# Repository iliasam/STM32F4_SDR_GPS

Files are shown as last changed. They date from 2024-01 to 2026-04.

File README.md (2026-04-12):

# STM32F4_SDR_GPS

Software GPS receiver for STM32F4  
See article (in Russian): https://habr.com/ru/articles/789382/  
You can find same project for **ESP32** here: https://github.com/iliasam/ESP32_SDR_GPS  
  
This is a demo project of STM32-based SDR GPS receiver.  
No additional factory/commercial "black box" GPS receiver is needed here - just connect MAX2769 (GNSS RF Frontend IC) to the STM32 MCU.  
All "raw" GPS signal processing is done at the STM32.  
Results of the GPS signal processing are send to the UART:   
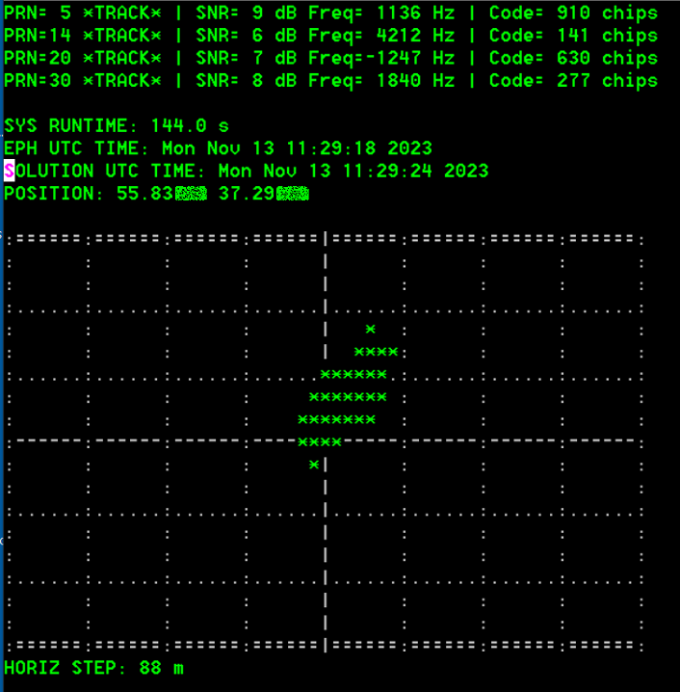
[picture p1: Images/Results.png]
  
This is what the receiver looks like:  
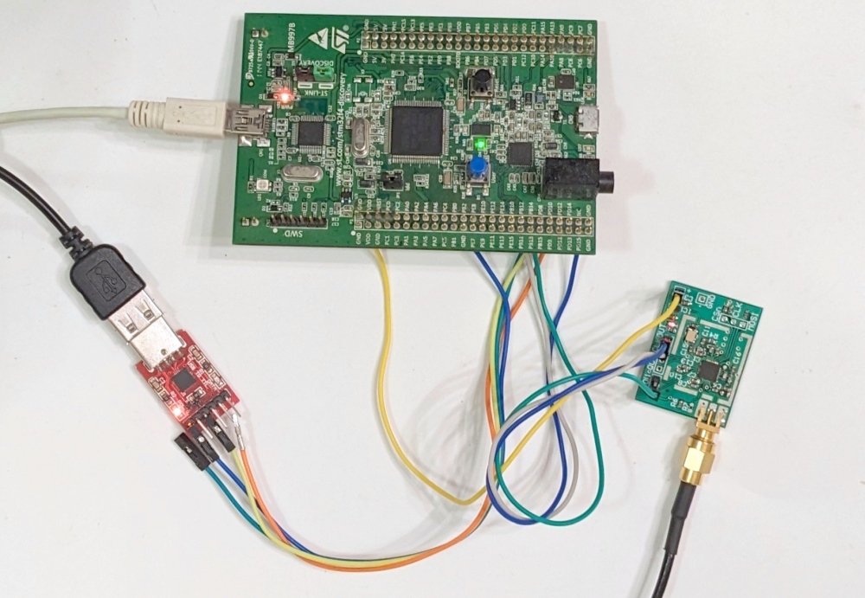
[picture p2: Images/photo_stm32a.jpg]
  
  
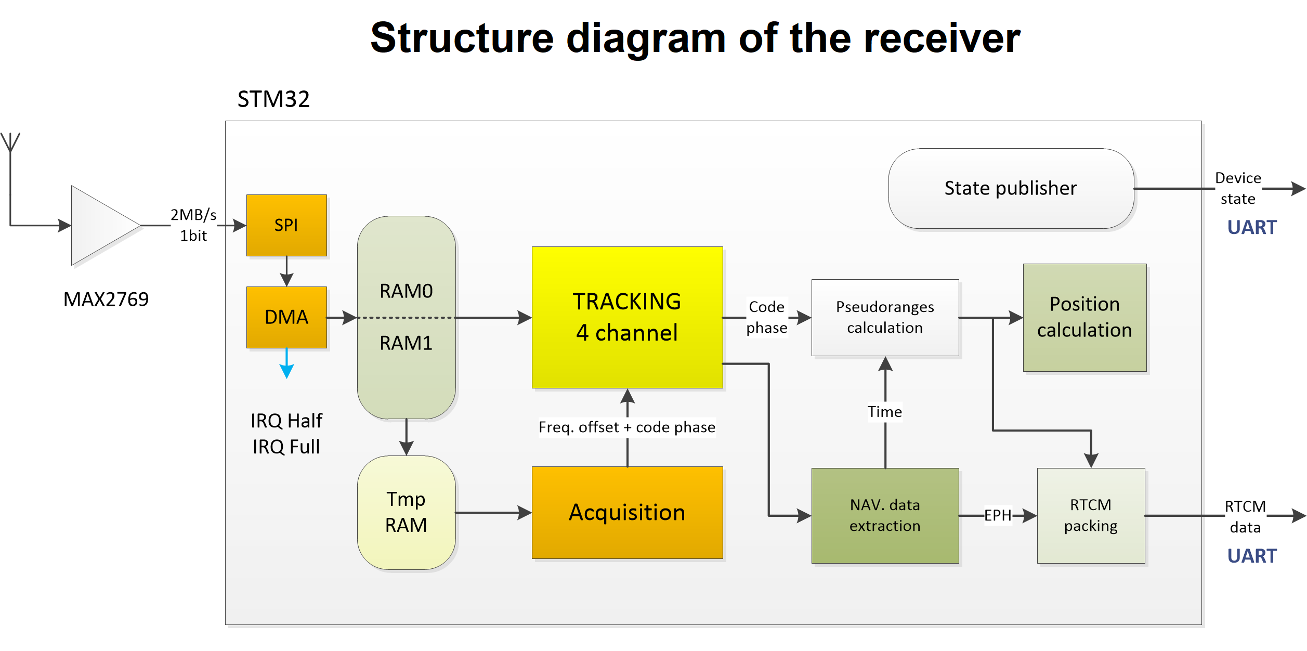
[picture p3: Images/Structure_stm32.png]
  
  
**Video about this project:**  
https://youtu.be/1hBnaDsQgMc  
  
Configured for STM32F4-DISCOVERY dev. board.  
-Os optimization is used here  

User must set PRN codes of 4 satellites in the code - before compiling FW (I'm too lazy to create real CLI).  
User can set Doppler frequency offsets in the code to make acquisition much faster.  
  
RF frontend pinout (See config.h):  
#define SPI_CLK_PIN             GPIO_Pin_13 //MAX2769 - CLKOUT  
#define SPI_MOSI_PIN            GPIO_Pin_15 //MAX2769 - I1  
Both - GPIOB  

Part of the code is taken from these projects:  
https://github.com/tomojitakasu/RTKLIB  
https://github.com/taroz/GNSS-SDRLIB

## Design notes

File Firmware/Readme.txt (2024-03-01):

"project_single_sat" - example of using only one satellite. PRN is set in "main.c"
It is simplier, but has less comments.
This firmware can parse only "Subframe 1".
Current time is printed when "Subframe 1" has received.  

UART is not used here, "printf" is redirected to the SWO line - see compiler options.
Stack - 0x2000
Heap - 0x200

Compiler output:
30 642 bytes of readonly  code memory 
   220 bytes of readonly  data memory 
89 713 bytes of readwrite data memory 

Example of SWO output:
SAT=5
FINAL FREQ=1000 Hz
FINAL ACQ (SRCH_3) CODE=1990
START PRE_TRACK
FOUND TRACK PHASE=1991
PREAMBLE!
POLAR. FOUND
SUB ID=2
PREAMBLE!
SUB ID=3
PREAMBLE!
SUB ID=4
PREAMBLE!
SUB ID=5
PREAMBLE!
SUB ID=1
Curr. Time = Mon Nov 13 11:28:18 2023
PREAMBLE!
SUB ID=2

*********************

"project_main" - example of using 4 satellites, including localization. PRN is set in "main.c"

RTCM/Receiving state information is send to the UART, but "printf" is still redirected to the SWO line.

Stack - 0x2000
Heap - 0x1000 (needed for localization)

Compiler output:
 67 978 bytes of readonly  code memory 
    301 bytes of readonly  data memory 
105 958 bytes of readwrite data memory 

******************

IAR 7.50 is used here

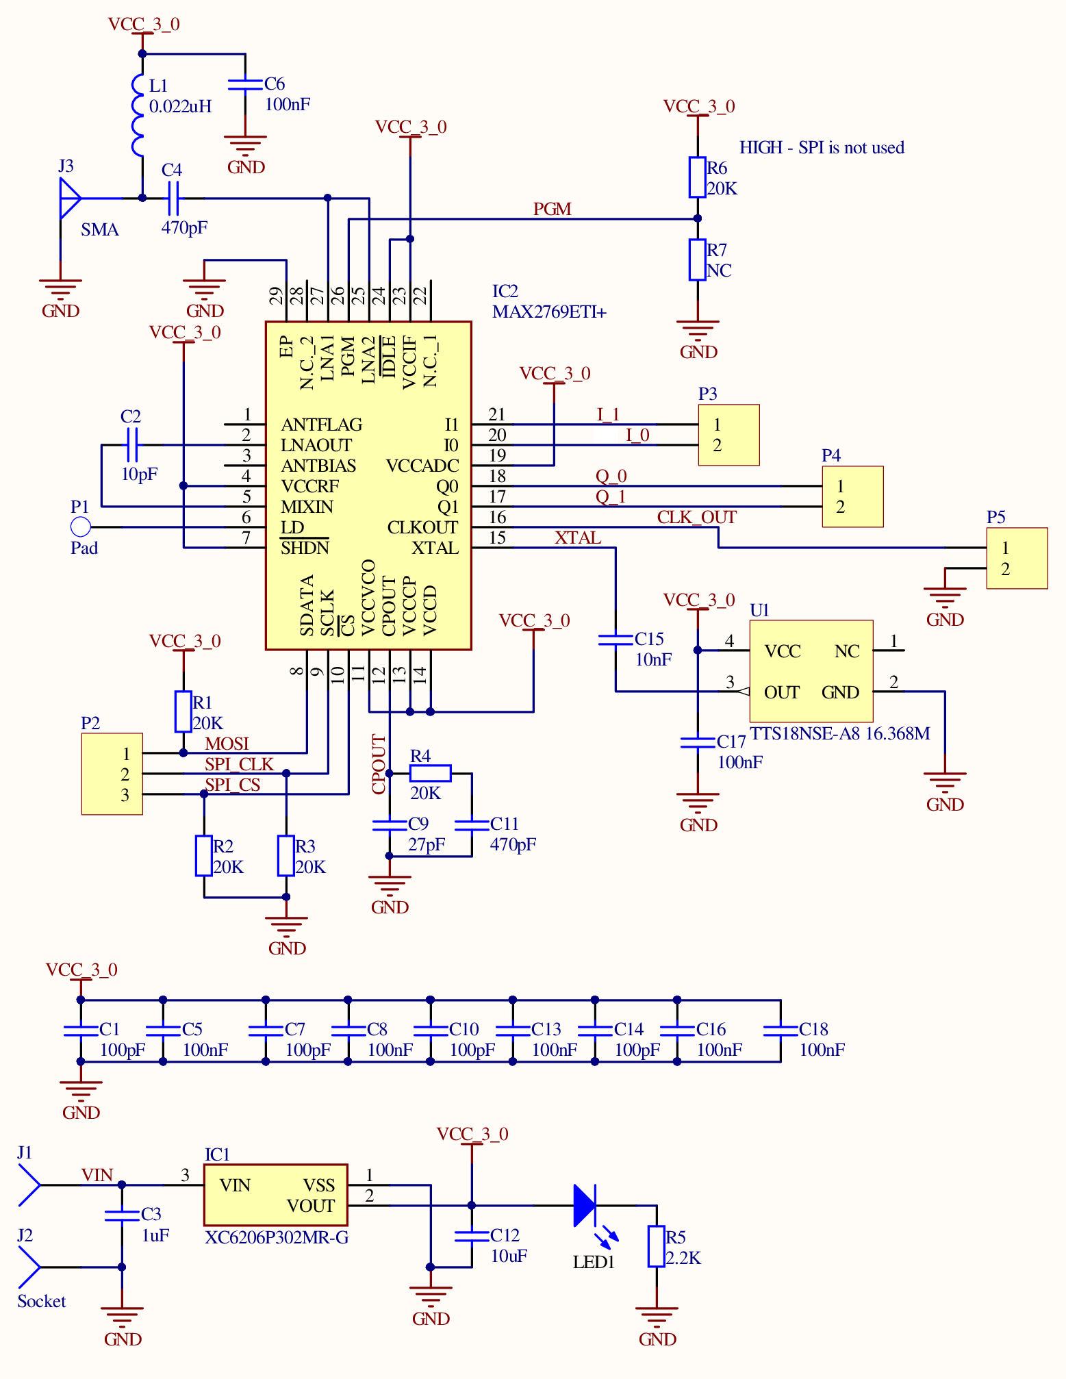
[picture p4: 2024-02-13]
RF_Frontend/schematic.png

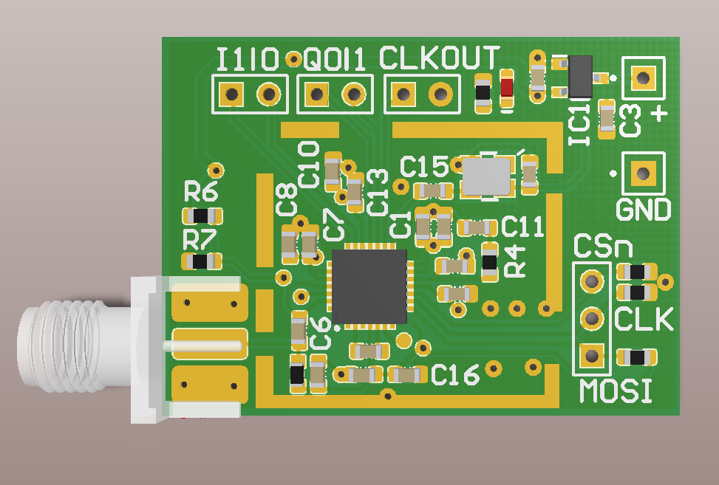
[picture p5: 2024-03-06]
RF_Frontend/image.png

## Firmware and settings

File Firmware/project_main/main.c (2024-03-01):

//Single satellite acquisition and tracking. 
//Printf is using semihosting via SWO (configured in )

/* Includes ------------------------------------------------------------------*/
#include "main.h"
#include "stm32f4xx_rcc.h"
#include "delay_us_timer.h"
#include "gps_misc.h"
#include "config.h"
#include "signal_capture.h"
#include "common_ram.h"
#include "acquisition.h"
#include "tracking.h"
#include "gps_master.h"
#include "uart_comm.h"
#include "print_state.h"
#include "keys_controlling.h"
#include <stdio.h>
#include <stdlib.h>
#include <math.h>
#include <string.h>

#if (ENABLE_RTCM_SEND)
  #include "obs_publish.h"
#endif

#if (ENABLE_CALC_POSITION)
  #include "solving.h"
#endif

/* Private typedef -----------------------------------------------------------*/
/* Private define ------------------------------------------------------------*/
/* Private macro -------------------------------------------------------------*/
/* Private variables ---------------------------------------------------------*/
gps_ch_t gps_channels[GPS_SAT_CNT];

/* Private function prototypes -----------------------------------------------*/
void main_process_acq_data(void);

void main_slow_data_proc(void);
void main_fast_data_proc(void);

/* Private functions ---------------------------------------------------------*/

int main(void)
{
  RCC_ClocksTypeDef RCC_Clocks;
  RCC_GetClocksFreq(&RCC_Clocks);
  NVIC_PriorityGroupConfig(NVIC_PriorityGroup_0); //4 bits for subpriority
  dwt_init();
  
  gps_fill_summ_table();
  
  memset(&gps_channels[0], 0, sizeof(gps_channels));
  
  //solve_test();
  
  // user can enter known doppler frequency to make acquisition much faster
  gps_channels[0].prn = 5;
  gps_channels[0].acq_data.given_freq_offset_hz = 900;
  gps_channell_prepare(&gps_channels[0]);
  
  gps_channels[1].prn = 14;
  gps_channels[1].acq_data.given_freq_offset_hz = 4000;
  gps_channell_prepare(&gps_channels[1]);
  
  gps_channels[2].prn = 20;
  gps_channels[2].acq_data.given_freq_offset_hz = -1000;
  gps_channell_prepare(&gps_channels[2]);
  
  gps_channels[3].prn = 30;
  gps_channels[3].acq_data.given_freq_offset_hz = 2000;
  gps_channell_prepare(&gps_channels[3]);
  
#if (ENABLE_CALC_POSITION)
  gps_pos_solve_init(gps_channels);
#endif
  
  uart_init();
  keys_init();
  signal_capture_init();
  
  signal_capture_need_data_copy();
  print_state_prepare(gps_channels);
  
  while(1)
  {
    uint8_t need_slow = gps_master_need_acq();
    if (need_slow > 0)
    {
      //Not realtime
      main_slow_data_proc();
    }
    else
    {
      //Realtime!
      uint8_t have_new_data = signal_capture_have_irq();
      if (have_new_data)
      {
        main_fast_data_proc();
      }
    }
    key_handling();
  }//end of while(1)
  
}//end of main()

//*********************************

// Acqusition data capure and process - not realtime
void main_slow_data_proc(void)
{
  uint8_t have_data = signal_capture_check_copied();
  if (have_data == 0)
  {
    //wait for IRQ
    while (signal_capture_have_irq() == 0) 
    {
      asm("nop");
    }
    
    //Process IRQ, data copy
    signal_capture_handling();
  }
  else
  {
    //have new data
    main_process_acq_data();
    signal_capture_need_data_copy();
  }
}

//Tracking
void main_fast_data_proc(void)
{
  uint8_t* signal_p = signal_capture_get_ready_buf();
  uint32_t time_cnt = signal_capture_get_packet_cnt();
  
  //4 channel multiplexing
  uint32_t index_big = time_cnt % (TRACKING_CH_LENGTH * GPS_SAT_CNT + 1); //real index, 0-16 range
  
  uint8_t sat_index = index_big / TRACKING_CH_LENGTH;
  if (sat_index >= GPS_SAT_CNT)
    sat_index = 0;
  
  uint32_t index = 0;
  if (index_big == (TRACKING_CH_LENGTH * GPS_SAT_CNT))
    index = 0xFF;
  else
  {
    index = index_big % TRACKING_CH_LENGTH;
  }
  
  //"index" can be 0-3 or 0xFF
  gps_tracking_process(&gps_channels[sat_index], signal_p, (uint8_t)index);
  
  gps_master_handling(gps_channels, index);
}


// Acquisition data process
// Can be long!
void main_process_acq_data(void)
{
  uint8_t* signal_p = signal_capture_get_copy_buf();
  acquisition_process(&gps_channels[0], signal_p);
  gps_master_handling(gps_channels, 0);
}

///////////////////////////////////

/*
int putchar(int c)
{
  return c;    
}
*/


void delay_ms(uint32_t ms)
{
  volatile uint32_t nCount;
  RCC_ClocksTypeDef RCC_Clocks;
  RCC_GetClocksFreq (&RCC_Clocks);
  nCount=(RCC_Clocks.HCLK_Frequency/10000)*ms;
  for (; nCount!=0; nCount--);
}

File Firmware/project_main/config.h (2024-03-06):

#ifndef _CONFIG_H
#define _CONFIG_H

//MCU speed is 168MHz
#define CPU_TICKS_US            (168)

#define SPI_NAME                SPI2
#define SPI_PRESCALER           SPI_BaudRatePrescaler_4
#define SPI_DMA_STREAM          DMA1_Stream3
#define SPI_DMA_CH              DMA_Channel_0
#define SPI_DMA_IRQ             DMA1_Stream3_IRQn
#define SPI_DMA_IRQ_HANDLER     DMA1_Stream3_IRQHandler

#define SPI_GPIO_CLK            RCC_AHB1Periph_GPIOB
#define SPI_CLK_PIN             GPIO_Pin_13 //MAX2769 - CLKOUT
#define SPI_MOSI_PIN            GPIO_Pin_15 //Slave Input! MAX2769 - I1 - sign
#define SPI_CLK_PIN_SRC         GPIO_PinSource13
#define SPI_MOSI_PIN_SRC        GPIO_PinSource15
#define SPI_AFIO                GPIO_AF_SPI2
#define SPI_GPIO                GPIOB


#define IF_FREQ_HZ              (int)(4092000)
#define SPI_BAUDRATE_HZ         (int)(16368000)
#define PRN_SPEED_HZ            1000 //1ms period
#define BITS_IN_PRN             (SPI_BAUDRATE_HZ / PRN_SPEED_HZ) //16Kbit
#define PRN_SPI_WORDS_CNT       (BITS_IN_PRN / 16) //1023 16bit words
#define PRN_LENGTH              1023 //in chips

#define ENABLE_RTCM_SEND        0

//Calculate receiver position by observations
#define ENABLE_CALC_POSITION    1

// Accurate code phase averaging
#define ENABLE_CODE_FILTER      1
//Number of measurements, speed is 25 measurements in one channel per 100ms
#define CODE_FILTER_LENGTH      100


#define ACQ_SEARCH_FREQ_HZ      (7000) //Frequency Search zone is x2. Doppler offset
#define ACQ_SEARCH_STEP_HZ      (500)
/// Number of freq steps
#define ACQ_COUNT       (ACQ_SEARCH_FREQ_HZ * 2 / ACQ_SEARCH_STEP_HZ + 1)

/// 1 step is 0.5 of chip
#define ACQ_PHASE1_HIST_STEP	(64)
#define ACQ_PHASE1_HIST_SIZE	((PRN_LENGTH + 1) * 2 / ACQ_PHASE1_HIST_STEP) //32

#define PRE_TRACK_POINTS_MAX_CNT        30

//#define IF_NCO_STEP_HZ        ((float)SPI_BAUDRATE_HZ / (float)(1 << 32)) //NCO accumulator is 32bit
#define IF_NCO_STEP_HZ	        (0.003810972f)

// Number of analysed PRN periods in one channal
#define TRACKING_CH_LENGTH      4

//Number of used satellites
#define GPS_SAT_CNT	        4

#define TRACKING_DLL1_C1        (1.0f)
#define TRACKING_DLL1_C2        (300.0f)

#define TRACKING_PLL1_C1        (4.0f)
#define TRACKING_PLL1_C2        (3000.0f)

#define TRACKING_PLL2_C1        (8.0f)
#define TRACKING_PLL2_C2        (5000.0f)

#define TRACKING_FLL1_C1        (200.0f)
#define TRACKING_FLL1_C2        (2000.0f)

#define GPS_BUILD_WEEK          2290 //NOV 2023

//*************************************************************************

//PRIMARY UART - sending RTCM

#define PRIMARY_UART_NAME       USART2
#define PRIMARY_UART_AF_NAME    GPIO_AF_USART2
#define PRIMARY_UART_BAUDRATE   115200

#define PRIMARY_UART_GPIO_CLK   RCC_AHB1Periph_GPIOA
#define PRIMARY_UART_CLK        RCC_APB1Periph_USART2

#define PRIMARY_UART_RX_PIN     GPIO_Pin_3
#define PRIMARY_UART_RX_PIN_SRC GPIO_PinSource3
#define PRIMARY_UART_RX_GPIO    GPIOA

#define PRIMARY_UART_TX_PIN     GPIO_Pin_2
#define PRIMARY_UART_TX_PIN_SRC GPIO_PinSource2
#define PRIMARY_UART_TX_GPIO    GPIOA

#define PRIMARY_UART_IRQ_HANDLER      USART2_IRQHandler

#define PRIMARY_DMA_RCC         RCC_AHB1Periph_DMA1
#define PRIMARY_DMA_TX_STREAM   DMA1_Stream6
#define PRIMARY_DMA_FLAG        DMA_FLAG_TCIF6
#define PRIMARY_DMA_TX_CH       DMA_Channel_4

//SECONDARY UART - sending GPS status to the terminal emulator

#define SECONDARY_UART_NAME     USART3
#define SECONDARY_UART_AF_NAME  GPIO_AF_USART3
#define SECONDARY_UART_BAUDRATE 115200

#define SECONDARY_UART_GPIO_CLK RCC_AHB1Periph_GPIOD
#define SECONDARY_UART_CLK      RCC_APB1Periph_USART3

#define SECONDARY_UART_RX_PIN   GPIO_Pin_9
#define SECONDARY_UART_RX_PIN_SRC GPIO_PinSource9
#define SECONDARY_UART_RX_GPIO  GPIOD

#define SECONDARY_UART_TX_PIN   GPIO_Pin_8
#define SECONDARY_UART_TX_PIN_SRC GPIO_PinSource8
#define SECONDARY_UART_TX_GPIO  GPIOD

#define SECONDARY_UART_IRQ_HANDLER      USART3_IRQHandler

#define SECONDARY_DMA_RCC       RCC_AHB1Periph_DMA1
#define SECONDARY_DMA_TX_STREAM DMA1_Stream4
#define SECONDARY_DMA_FLAG      DMA_FLAG_TCIF4
#define SECONDARY_DMA_TX_CH     DMA_Channel_7


//--------------------------
//Debug only
#define LED4_PIN                GPIO_Pin_12
#define LED4_GPIO_PORT          GPIOD

#define BUTTON1_PIN             GPIO_Pin_0
#define BUTTON1_GPIO            GPIOA


#endif //_CONFIG_H

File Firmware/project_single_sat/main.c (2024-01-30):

//Single satellite acquisition and tracking. 
//Printf is using semihosting via SWO (configured in project config)
//MCU Core Freq is 168 Mhz

/* Includes ------------------------------------------------------------------*/
#include "main.h"
#include "stm32f4xx_rcc.h"
#include "delay_us_timer.h"
#include "simulator.h"
#include "gps_misc.h"
#include "config.h"
#include "signal_capture.h"
#include "common_ram.h"
#include "acquisition.h"
#include "tracking.h"
#include <stdio.h>
#include <stdlib.h>
#include <math.h>
#include <string.h>

/* Private typedef -----------------------------------------------------------*/
/* Private define ------------------------------------------------------------*/
/* Private macro -------------------------------------------------------------*/
/* Private variables ---------------------------------------------------------*/


volatile int16_t test_res = 0;
volatile static uint32_t diff_main = 0;

gps_ch_t gps_channel1;
/* Private function prototypes -----------------------------------------------*/
void gps_new_data_handling(void);

uint8_t need_slow_data_proc(void);
void main_slow_data_proc(void);
void main_fast_data_proc(void);

/* Private functions ---------------------------------------------------------*/

int main(void)
{
  RCC_ClocksTypeDef RCC_Clocks;
  RCC_GetClocksFreq(&RCC_Clocks);
  NVIC_PriorityGroupConfig(NVIC_PriorityGroup_0); //4 bits for subpriority
  dwt_init();
  
  gps_fill_summ_table();
  
  memset(&gps_channel1, 0, sizeof(gps_channel1));
  gps_channel1.prn = 5;
  // user can enter known doppler frequency to make acquisition much faster
  //gps_channel1.acq_data.given_freq_offset_hz = 1200; 
  gps_channell_prepare(&gps_channel1);
  
  delay_ms(100);
  printf("SAT=%d\n", gps_channel1.prn);
  signal_capture_init();
  
  /*
  //Testing, need to add "simulator.c" to the project
  uint16_t* signal_p = sim_generate_data();
  sim_add_noise(signal_p, 45);
  
  gps_generate_prn_data2(&gps_channel1, tmp_prn_data, 0);
  gps_shift_to_zero_freq((uint8_t*)signal_p, (uint8_t*)tmp_data_i, (uint8_t*)tmp_data_q, IF_FREQ_HZ + 2000);
  uint16_t avr_val;
  uint16_t best_phase = 0;
  correlation_search(tmp_prn_data, tmp_data_i, tmp_data_q, 0, (PRN_LENGTH * 2), &avr_val, &best_phase);
  */
  
  signal_capture_need_data_copy();
  
  while(1)
  {
    uint8_t need_slow = need_slow_data_proc();
    if (need_slow)
    {
      //Not realtime
      main_slow_data_proc();
    }
    else
    {
      //Realtime!
      uint8_t have_new_data = signal_capture_have_irq();
      if (have_new_data)
      {
        main_fast_data_proc();
      }
    }
  }//end of while(1)
  
}//end of main()

//*********************************

void main_fast_data_proc(void)
{
  uint8_t* signal_p = signal_capture_get_ready_buf();
  uint32_t time_cnt = signal_capture_get_packet_cnt();
  
  //A kind of simulation of 4 channel multiplexing
  uint32_t index_big = time_cnt % (TRACKING_CH_LENGTH * GPS_SAT_CNT + 1); //real index, 0-16 range
  uint32_t index = index_big % TRACKING_CH_LENGTH; //in 0-3 range
  if (index_big == (TRACKING_CH_LENGTH * GPS_SAT_CNT))//dummy step
    index = 0xFF;
  
  //So "index" can be 0-3 or 0xFF
  gps_tracking_process(&gps_channel1, signal_p, (uint8_t)index);
}


// Acqusition data capure and process - not realtime
void main_slow_data_proc(void)
{
  uint8_t have_data = signal_capture_check_copied();
  if (have_data == 0)
  {
    //wait for IRQ
    while (signal_capture_have_irq() == 0) 
    {
      asm("nop");
    }
    
    //Process IRQ, data copy
    signal_capture_handling();
  }
  else
  {
    //have new data
    gps_new_data_handling();
    signal_capture_need_data_copy();
  }
}


//Return 1 when acq. data processing is needed
uint8_t need_slow_data_proc(void)
{
  if (gps_channel1.acq_data.state < GPS_ACQ_CODE_PHASE_SEARCH3_DONE)
    return 1;
  
  return 0;
}

// Acquisition data process
// Can be long!
void gps_new_data_handling(void)
{
  uint8_t* signal_p = signal_capture_get_copy_buf();
  acquisition_process(&gps_channel1, signal_p);
  
  if (gps_channel1.acq_data.state == GPS_ACQ_FREQ_SEARCH_DONE)
  {
    printf("FINAL FREQ=%d Hz\n", gps_channel1.acq_data.found_freq_offset_hz);
  }
  
  if (gps_channel1.acq_data.state == GPS_ACQ_CODE_PHASE_SEARCH3_DONE)
  {
    printf("FINAL ACQ (SRCH_3) CODE=%d\n", gps_channel1.acq_data.found_code_phase);
    gps_channel1.acq_data.state = GPS_ACQ_DONE;
    gps_channel1.tracking_data.state = GPS_NEED_PRE_TRACK;
  }
}
///////////////////////////////////

/*
int putchar(int c)
{
  return c;    
}
*/


void delay_ms(uint32_t ms)
{
  volatile uint32_t nCount;
  RCC_ClocksTypeDef RCC_Clocks;
  RCC_GetClocksFreq (&RCC_Clocks);
  nCount=(RCC_Clocks.HCLK_Frequency/10000)*ms;
  for (; nCount!=0; nCount--);
}

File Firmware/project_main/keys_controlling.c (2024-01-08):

/* Includes ------------------------------------------------------------------*/
#include "keys_controlling.h"
#include "stm32f4xx_gpio.h"
#include "signal_capture.h" //to get time
#include "main.h"
#include "string.h"
#include "config.h"

/* Private typedef -----------------------------------------------------------*/
/* Private define ------------------------------------------------------------*/
//Time in ms
#define KEY_HOLD_TIME            900

//Time in ms
#define KEY_PRESSED_TIME         50

//Time in ms
#define KEY_RELEASE_TIME         50

//Time in ms
#define KEYS_STARTUP_DELAY      500

#define START_TIMER(x, duration)  (x = (signal_capture_get_packet_cnt() + duration))
#define TIMER_ELAPSED(x)  ((signal_capture_get_packet_cnt() > x) ? 1 : 0)

/* Private macro -------------------------------------------------------------*/
/* Private variables ---------------------------------------------------------*/
key_item_t key_up;

uint32_t keys_startup_timer = 0;
uint8_t keys_startup_lock_flag = 1;

/* Private function prototypes -----------------------------------------------*/
uint8_t key_up_presed = 0;

/* Private functions ---------------------------------------------------------*/

void keys_init(void)
{
  RCC_AHB1PeriphClockCmd(RCC_AHB1Periph_GPIOA, ENABLE);
  key_up.gpio_name = BUTTON1_GPIO;
  key_up.pin_name = BUTTON1_PIN;
  keys_functons_init_hardware(&key_up);
  START_TIMER(keys_startup_timer, KEYS_STARTUP_DELAY);
}

void key_handling(void)
{
  keys_functons_update_key_state(&key_up);
  
  if (TIMER_ELAPSED(keys_startup_timer) == 0)
    return; //delay before startup
  else
  {
      keys_startup_lock_flag = 0;
  }
  

  if ((key_up.prev_state == KEY_PRESSED) && 
      (key_up.state == KEY_WAIT_FOR_RELEASE))
  {
    key_up_presed = 1;
  }
  
  if ((key_up.prev_state == KEY_PRESSED) && 
      (key_up.state == KEY_HOLD))
  {

  }
}

//*****************************************************************************

// Initialize single key pin
void keys_functons_init_hardware(key_item_t* key_item)
{
  if (key_item == NULL)
    return;
  
  GPIO_InitTypeDef GPIO_InitStructure;
  
  GPIO_StructInit(&GPIO_InitStructure);
  GPIO_InitStructure.GPIO_Mode = GPIO_Mode_IN;
  GPIO_InitStructure.GPIO_PuPd = GPIO_PuPd_DOWN;
  GPIO_InitStructure.GPIO_Pin = key_item->pin_name;
  GPIO_Init(key_item->gpio_name, &GPIO_InitStructure);
  
  key_item->state = KEY_RELEASED;
}

void keys_functons_update_key_state(key_item_t* key_item)
{
  key_item->prev_state = key_item->state;
  
  if ((key_item->gpio_name->IDR & key_item->pin_name) != 0)
    key_item->current_state = 1;
  else
    key_item->current_state = 0;
  
  if ((key_item->state == KEY_RELEASED) && (key_item->current_state != 0))
  {
    //key presed now
    key_item->state = KEY_PRESSED_WAIT;
    key_item->key_timestamp = signal_capture_get_packet_cnt();
    return;
  }
  
  if (key_item->state == KEY_PRESSED_WAIT)
  {
    uint32_t delta_time = signal_capture_get_packet_cnt() - key_item->key_timestamp;
    if (delta_time > KEY_PRESSED_TIME)
    {
      if (key_item->current_state != 0)
        key_item->state = KEY_PRESSED;
      else
        key_item->state = KEY_RELEASED;
    }
    return;
  }
  
  if ((key_item->state == KEY_PRESSED) || (key_item->state == KEY_HOLD))
  {
    // key not pressed
    if (key_item->current_state == 0)
    {
      key_item->state = KEY_WAIT_FOR_RELEASE;// key is locked here
      key_item->key_timestamp = signal_capture_get_packet_cnt();
      return;
    }
  }
  
  if (key_item->state == KEY_WAIT_FOR_RELEASE)
  {
    uint32_t delta_time = signal_capture_get_packet_cnt() - key_item->key_timestamp;
    if (delta_time > KEY_RELEASE_TIME)
    {
      key_item->state = KEY_RELEASED;
      return;
    }
  }
  
  if ((key_item->state == KEY_PRESSED) && (key_item->current_state != 0))
  {
    //key still presed now
    uint32_t delta_time = signal_capture_get_packet_cnt() - key_item->key_timestamp;
    if (delta_time > KEY_HOLD_TIME)
    {
      key_item->state = KEY_HOLD;
      return;
    }
  }
}

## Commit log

2024-01-03 Copyed fils from PC. Added sending RTCM to UART.
2024-01-08 Added key handling. Added acq. reset.
    [config.h, keys_controlling.c, main.c]
2024-01-18 Added printing position info.
2024-01-30 Testig SPI MOSI
2024-01-30 Improved working with SPI.
2024-02-03 Added code phase filter.
2024-02-13 Improved comments. Added project files.
    [PCB1.GBL, PCB1.GBO, PCB1.GBS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]
2024-02-29 Added SpiLight files. Renamed folder.
    [PCB1.GBL, PCB1.GBO, PCB1.GBS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]
2024-02-29 Gerber filles are packed to ZIP.
    [PCB1.GBL, PCB1.GBO, PCB1.GBS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]
2024-03-06 Updated gerbers.
